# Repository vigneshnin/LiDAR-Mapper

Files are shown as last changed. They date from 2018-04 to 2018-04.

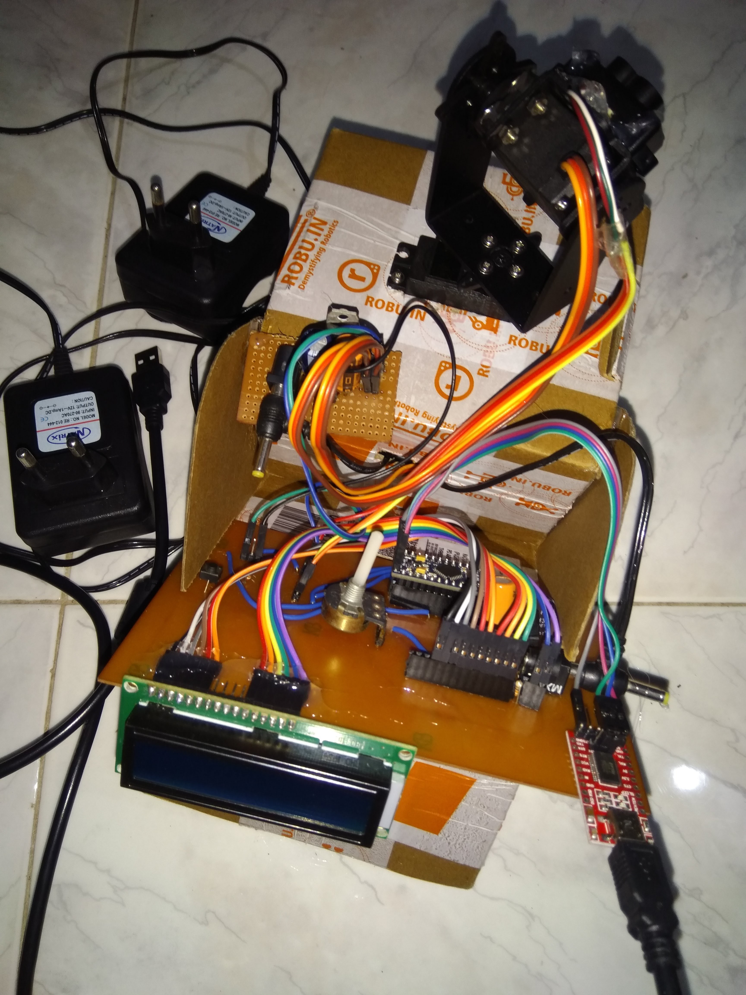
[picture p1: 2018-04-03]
IMG_20180305_001046.jpg

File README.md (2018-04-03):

# LiDAR-Mapper
A LiDAR 3D Mapping system which is very low cost at 5000₹(~80$) made using arduino.
The PCB is there in the LA3DMS folder. There are some errors in the pcb but it can be fixed by using jumpers.
You'll need an extra power supply for the servo motors (if you use mg995, smaller servo will work fine) because the one on the pcb is not powerful enough.
Use an arduino or FTDI programmer for the UART communication to transfer co-ordinate data to PC.
Use the .pde file with processing IDE to visualise the data.

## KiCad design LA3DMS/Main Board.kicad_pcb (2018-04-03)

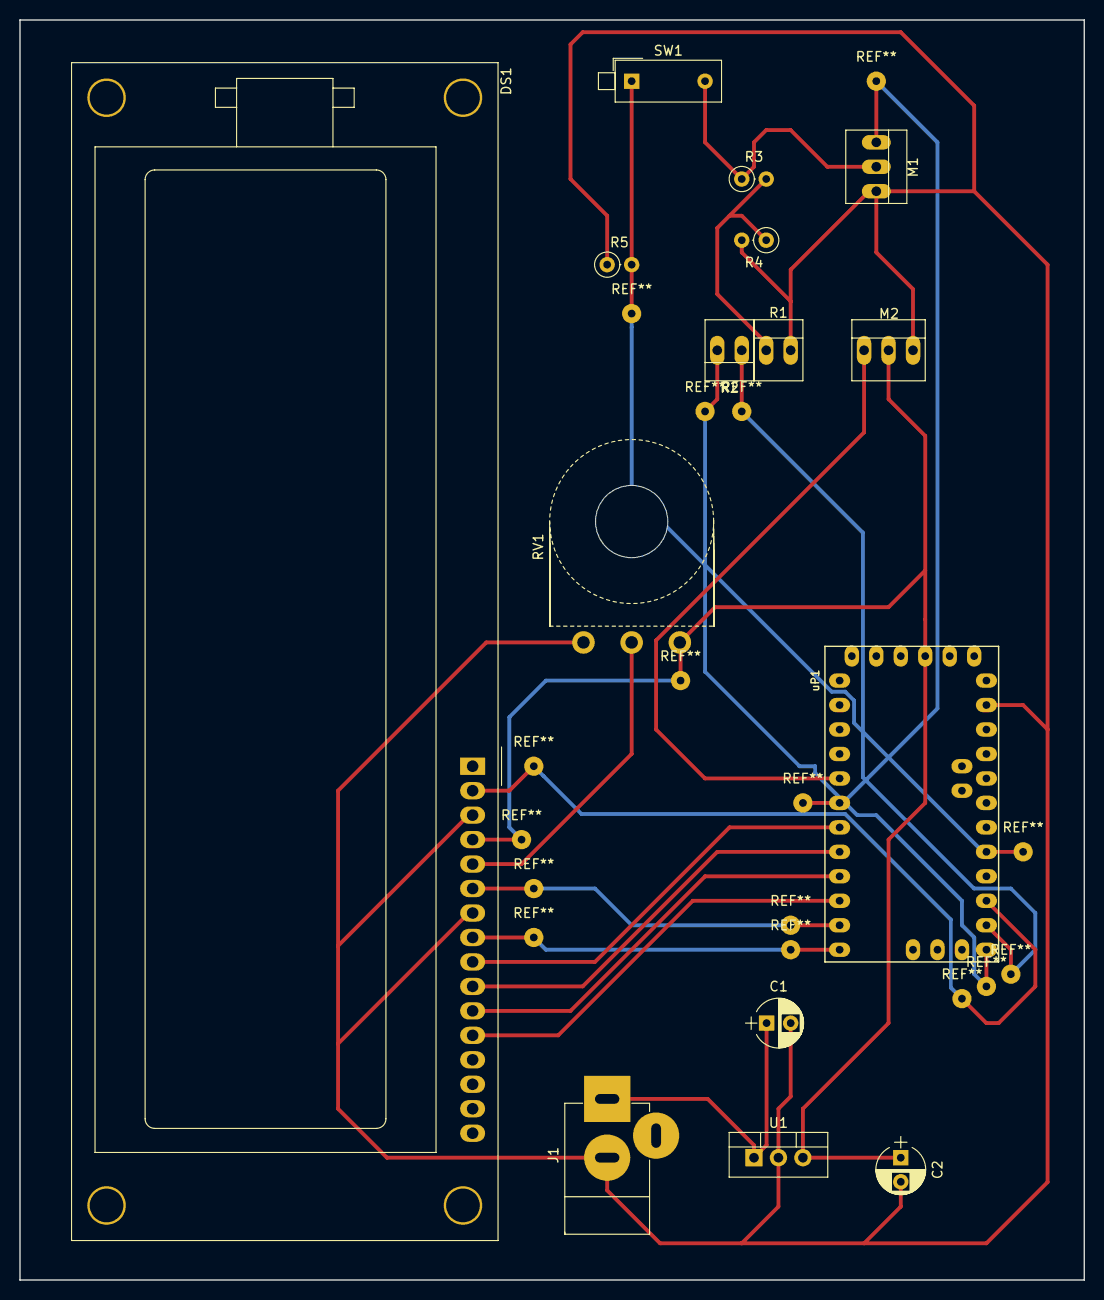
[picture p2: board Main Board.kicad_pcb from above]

Board: 2 copper layers, 110.5 x 130.8 mm, 15 parts (0 on the bottom side), 10 nets.

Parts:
C1, C2: CP; CP_Radial_D5.0mm_P2.50mm
DS1: HY1602E
J1: Barrel_Jack; JACK_ALIM
M1, M2: Motor_Servo; PINHEAD1-3
R1, R2: R; PINHEAD1-2
R3, R4, R5: R; R_Axial_DIN0207_L6.3mm_D2.5mm_P2.54mm_Vertical
RV1: POT; Potentiometer_Omeg_PC16PU_Horizontal_MountLS
SW1: SW_Push; SW_DIP_x1_W7.62mm_Piano
U1: L7805; TO-220-3_Vertical
uP1: ARDUPROMINI; pro_mini

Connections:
GND: C1.2, C2.2, DS1.3, DS1.7, J1.2, M1.3, M2.3, R1.2, R4.2, R5.1, RV1.3, U1.2, uP1.23
unnamed: C1.1, J1.1, U1.1
unnamed: C2.1, M1.2, M2.2, R3.1, SW1.2, U1.3, uP1.31
unnamed: DS1.5, RV1.2
unnamed: DS1.9, uP1.7
unnamed: DS1.10, uP1.8
unnamed: DS1.11, uP1.9
unnamed: DS1.12, uP1.10
unnamed: M2.1, uP1.5
unnamed: R1.1, R3.2, R4.1

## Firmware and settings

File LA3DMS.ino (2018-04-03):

//For Servo and controls
#include <Servo.h>
#include <LiquidCrystal.h>
//For Lidar
#include <SoftwareSerial.h>
#include "TFMini.h"

//Servo controls
Servo servoX;
Servo servoY;

//Lidar Controls
SoftwareSerial mySerial(10, 11);      // Uno RX (TFMINI TX), Uno TX (TFMINI RX)
TFMini tfmini;

LiquidCrystal lcd(8, 9, 4, 5, 6, 7);



// Minimum and maximum servo angle in degrees
// Modify to avoid hitting limits imposed by pan/tilt bracket geometry
int minPosX = 0;
int maxPosX = 180;
int minPosY = 0;
int maxPosY = 90;

//int buttonPin = A0;
//int buttonValue = 0;
//int buttonThreshold = 50;
int lastPosX = 0;
int lastPosY = 0;
int loopCount = 0;
int radius = 0;
int lastRadius = 0;
//boolean selectButtonPressed = false;
boolean scanning = true;
boolean scanDirection = false;
int scanIncrement = 1;
int posX = (maxPosX + minPosX) / 2;
int posY = minPosY;
float pi = 3.14159265;
float deg2rad = pi / 180.0;




void setup() {
  // put your setup code here, to run once:
  
  // Step 1: Initialize hardware serial port (serial debug port)
  Serial.begin(115200);
  // wait for serial port to connect. Needed for native USB port only
  while (!Serial);
     
  Serial.println ("Initializing...");

  // Step 2: Initialize the data rate for the SoftwareSerial port
  mySerial.begin(TFMINI_BAUDRATE);

  // Step 3: Initialize the TF Mini sensor
  tfmini.begin(&mySerial);    

  //Initialize LCD
  lcd.begin(16, 2);
  
  
  //Setup Servo Pins
  servoX.attach(2);
  servoY.attach(3);
  servoX.write(posX);
  servoY.write(posY);
  
  //Serial Monitor setup
  //Serial.begin(9600);

}

void loop() {
  // put your main code here, to run repeatedly:

//  buttonValue = analogRead(buttonPin);

  if (scanning) {
    if (scanDirection) {
      posX += scanIncrement;
    } else {
      posX -= scanIncrement;
    }
    if (posX > maxPosX || posX < minPosX) {
      // hit limit X limit, reverse auto scan direction
      scanDirection = !scanDirection;
      posY += scanIncrement;
      if (posY > maxPosY) {
        // completed auto scan, return to manual scan mode
        scanning = false;
        updateModeDisplay();
      }
    }
  } else {

    Serial.print("Not scanning check scanninf bool");
    lcd.print("End Of Scan ");
    
/*    if (abs(buttonValue - 741) < buttonThreshold) {
      if (!selectButtonPressed) {
        // switch to auto scan mode
        selectButtonPressed = true;
        scanning = true;
        posX = minPosX;
        posY = minPosY;
        scanDirection = true;
        updateModeDisplay();
      }
    } else if (abs(buttonValue - 505) < buttonThreshold) {
      // manual scan left
      posX += 1;
    } else if (abs(buttonValue - 329) < buttonThreshold) {
      // manual scan down
      posY -= 1;
    } else if (abs(buttonValue - 145) < buttonThreshold) {
      // manual scan up
      posY += 1;
    } else if (abs(buttonValue - 0) < buttonThreshold) {
      // manual scan right
      posX -= 1;
    } else {
      selectButtonPressed = false;
    } */
  }

  posX = min(max(posX, minPosX), maxPosX);
  posY = min(max(posY, minPosY), maxPosY);
  bool moved = moveServos();
  displayPosition();

  loopCount += 1;
  if (loopCount % 100 == 0) {
    // recalibrate scanner every 100 scans
    radius = tfmini.getDistance();
  } 
  else {
    radius = tfmini.getDistance();
  } 
  if (abs(radius - lastRadius) > 2)
  {
    lastRadius = radius;
    lcd.setCursor(8, 0);
    lcd.print("D:" + String(radius / 100.0, 2) + "  ");
  }
  if (scanning || moved) {
    float azimuth = posX * deg2rad;
    float elevation = (180 - maxPosY + posY) * deg2rad;
    double x = radius * sin(elevation) * cos(azimuth);
    double y = radius * sin(elevation) * sin(azimuth);
    double z = radius * cos(elevation);
    Serial.println(String(x, 5) + " " + String(y, 5) + " " + String(-z, 5));
  }

  
}

//Functions------------
bool moveServos()
{
  bool moved = false;
  static int lastPosX;
  static int lastPosY;
  int delta = 0;  
  if (posX != lastPosX) {
    delta += abs(posX - lastPosX);
    servoX.write(posX);
    lastPosX = posX;
    moved = true;
  }
  if (posY != lastPosY) {
    delta += abs(posY - lastPosY);
    servoY.write(posY);
    lastPosY = posY;
    moved = true;
  }
  delay(30);
  return moved;
}

void displayPosition()
{
  static int lastPosX;
  static int lastPosY;
  if (posX != lastPosX) {
    lcd.setCursor(0, 0);
    lcd.print("X:" + String(posX) + "  ");
    lastPosX = posX;
  }
  if (posY != lastPosY) {
    lcd.setCursor(0, 1);
    lcd.print("Y:" + String(posY) + "  ");
    lastPosY = posY;
  }  
}

void updateModeDisplay()
{
  lcd.setCursor(8, 1);
  if (scanning) {
    lcd.print("Scanning");
  } else {
    lcd.print("Not Scanning");
  }
}

//------------------------------------ROUGH WORK----------------------------------------


//____________________________________________________________________

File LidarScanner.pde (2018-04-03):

// LidarScanner.pde Processing sketch
// http://www.qcontinuum.org/lidar

// Load sketch into Processing, available from:
// https://processing.org/

// This sketch accepts XYZ coordinates from Arduino LIDAR scanner
// and displays them graphically as a 3D point cloud that you can
// pan, zoom, and rotate using keyboard.

import processing.serial.*;

Serial serial;
int serialPortNumber = 32;
float angle = 6.5f;
float angleIncrement = 0;
float xOffset = 0.0;
float xOffsetIncrement = 0;
float yOffset = 0f;
float yOffsetIncrement = 0;
float scale = 2.6f;
float scaleIncrement = 0;
ArrayList<PVector> vectors;
int lastPointIndex = 0;
int lastPointCount = 0;

void setup() {
  size(800, 600, P3D);
  colorMode(RGB, 255, 255, 255);
  noSmooth();
  vectors = new ArrayList<PVector>();
  String[] serialPorts = Serial.list();
  String serialPort = serialPorts[serialPortNumber];
  println("Using serial port \"" + serialPort + "\"");
  println("To use a different serial port, change serialPortNumber:");
  printArray(serialPorts);
  serial = new Serial(this, serialPort, 115200);
}

void draw() {
  String input = serial.readStringUntil(10);
  if (input != null) {
    String[] components = split(input, ' ');
    if (components.length == 3) {
      vectors.add(new PVector(float(components[0]), float(components[1]), float(components[2])));
    }
  }
  background(0);
  translate(width/2, height/2, -50);
  rotateY(angle);
  int size = vectors.size();
  for (int index = 0; index < size; index++) {
    PVector v = vectors.get(index);
    if (index == size - 1) {
      // draw red line to show recently added LIDAR scan point
      if (index == lastPointIndex) {
        lastPointCount++;
      } else {
        lastPointIndex = index;
        lastPointCount = 0;
      }
      if (lastPointCount < 10) {
        stroke(255, 0, 0);
        line(xOffset, yOffset, 0, v.x * scale + xOffset, -v.z * scale + yOffset, -v.y * scale);
      }
    }
    stroke(255, 255, 255);
    point(v.x * scale + xOffset, -v.z * scale + yOffset, -v.y * scale);
  }
  angle += angleIncrement;
  xOffset += xOffsetIncrement;
  yOffset += yOffsetIncrement;
  scale += scaleIncrement;
}

void keyPressed() {
  if (key == 'q') {
    // zoom in
    scaleIncrement = 0.02f;
  } else if (key == 'z') {
    // zoom out
    scaleIncrement = -0.02f;
  } else if (key == 'a') {
    // move left
    xOffsetIncrement = -1f;
  } else if (key == 'd') {
    // move right
    xOffsetIncrement = 1f;
  } else if (key == 'w') {
    // move up
    yOffsetIncrement = -1f;
  } else if (key == 's') {
    // move down
    yOffsetIncrement = 1f;
  } else if (key =='x') {
    // erase all points
    vectors.clear();
  } else if (key == CODED) {
    if (keyCode == LEFT) {
      // rotate left
      angleIncrement = -0.015f;
    } else if (keyCode == RIGHT) {
      // rotate right
      angleIncrement = 0.015f;
    }
  }
}

void keyReleased() {
  if (key == 'q') {
    scaleIncrement = 0f;
  } else if (key == 'z') {
    scaleIncrement = 0f;
  } else if (key == 'a') {
    xOffsetIncrement = 0f;
  } else if (key == 'd') {
    xOffsetIncrement = 0f;
  } else if (key == 'w') {
    yOffsetIncrement = 0f;
  } else if (key == 's') {
    yOffsetIncrement = 0f;
  } else if (key == CODED) {
    if (keyCode == LEFT) {
      angleIncrement = 0f;
    } else if (keyCode == RIGHT) {
      angleIncrement = 0f;
    }
  }
}
